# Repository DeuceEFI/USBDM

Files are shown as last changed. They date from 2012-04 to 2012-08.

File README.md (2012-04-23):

# USBDM

JAG 04/16/2012 1500 EST (GMT-0500)

### Introduction

I did not invent the USBDM nor the TBDML or OSBDM that my version of the USBDM PCB is based on, I merely arranged the components so that a home user could etch and solder the components to create a USBDM at home.  This device allows the user to program a blank Freescale microcontroller or to debug the operation of a Freescale microcontroller through the microcontroller's BDM (Background Debug Mode) port.

### Goals

Core specs:

 * USB Type A male connector
 * This USBDM is USB bus powered and will power the target microcontroller (if the target board draws less than 100mA to program the target MCU).
 * No other BDM is necessary to program the Freescale MCU used on the USDBM board, you can program the initial USBDM program through the USB connector.
 * Low cost: components to build this version of the USBDM PCB are approximately $15 USD.
 * Software is available for Windows and Linux host systems from http://sourceforge.net/projects/usbdm/files/

PCB size is to be as small as possible to fit into a USB Type-A female socket on a laptop.

### Links:
 * Sourceforge description: http://usbdm.sourceforge.net/USBDM_V4.9/USBDM_JS16/html/index.html

### Features:

This version of the code & extended hardware provides the following features:

 * A single BDM interface for programming and debugging of the following targets:
   * HCS12 (including those without SYNC feature (e.g. 9S12DP256B)
   * HCS12X
   * HCS08
   * Coldfire V1 microcontrollers

 * No re-flashing of the BDM is required when changing between targets
 * Compatible IDEs
   * Codewarrior V10.1 (Eclipse version)
     * Tested on Windows-XP-32bit, Windows-7-32bit, Windows-7-64bit
     * Tested on Ubuntu-32-bit, Debian-32-bit
   * Codewarrior Legacy versions
   * Codewarrior Development Studio for HCS12(X) V5.1 & CW for Microcontrollers V6.3 (RS08 is not supported)
     * Tested on Windows-XP-32bit, Windows-Vista-32bit
   * Initial support for CodeSourcery Lite for Coldfire
     * Tested on Windows-XP-32bit

 * Trimming of target internal clock (Eclipse version or standalone programming tools only).
 * Higher USB communication speed cf. JB16 version BDMs (USB full speed cf. USB low speed)
 * Windows Vista/Windows 7 compatible
 * Linux compatible
 * Initial Firmware programming may be done without a BDM using the JS16 USB bootloader ROM.
 * The Firmware in the BDM may be automatically updated using an in-circuit-programming (ICP) feature.
 * Hardware is physically small
 * HCS12, HCS08, Coldfire V1 specific features:
   * Target reset detection & control (required for HC12 processors). This allows HC12 processors to be reset into BDM mode as required for debugging.
   * A higher BDM interface speed than the existing JB16 OSBDMs. Up to 56MHz. (BDM clock 28MHz).
   * Automatic re-connection. The software has an option to continuously update the interface speed to prevent loss of communication if the target BDM interface speed changes (as may occur with clock changes on some targets).
   * Control of BDM clock selection in HC12/HCS08/Coldfire microcontrollers. Most of these targets provide an alternative BDM clock selection. This can have advantages when connecting to high speed targets as the alternative clock may operate at a lower speed.
   * Trial-and-error determination of communication speed for earlier HC12 targets.
   *User prompting for target supply cycling with BKGD low as may be needed for HCS08 targets
 
### Status

For the most up to date status information for the project, refer to this README.md file which is maintained in sync with the schematics by a small team who verify each other's work.

### Changes

Please send any changes that you make to this USBDM back upstream to Andy Goss' copy at https://github.com/DeuceEFI/USBDM

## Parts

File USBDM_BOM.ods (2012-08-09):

Component | Quantity | Description | Manufacturer | Part# | Digikey# | Price Each | Sub-Total
C1,C7 | 2 | 100nF capacitor | TDK Corporation | FK20C0G1H104J | 445-4756-ND | $0.96 | $1.92
C2,C4 | 2 | 18pF capacitor | TDK Corporation | FK18C0G1H180J | 445-4762-ND | $0.29 | $0.58
C5,C6 | 2 | 10uF/10V Tantalum capacitor | Kemet | T356C106K010AT | 399-3631-ND | $1.30 | $2.60
C8 | 1 | 470nF capacitor | AVX Corporation | SR205E474MAR | 478-4858-ND | $0.44 | $0.44
D1 | 1 | Green 3mm LED | Kingbright Corporation | WP132XGD | 754-1201-ND | $0.14 | $0.14
P1 | 1 | USB-A Right Angle Plug | Molex Connector Corportation | 48037-0001 | WM17117-ND | $1.70 | $1.70
P2 | 1 | 6 Position 0.1” x 0.1” IDC Ribbon PCB | FCI | 69830-006LF | 609-3082-ND | $1.09 | $1.09
P3 | 1 | 6 Position IDC Socket | FCI | 71600-106LF | 609-2842-ND | $1.18 | $1.18
R1,R2 | 2 | 33 ohm 1% Metal Film resistor | Stackpole Electronics Inc | RNMF14FTC33R0 | S33CACT-ND | $0.14 | $0.28
R3,R5 | 2 | 100K ohm 1% Metal Film resistor | Stackpole Electronics Inc | RNMF18FTC100K | S100KCACT-ND | $0.15 | $0.30
R4 | 1 | 1.5K ohm 1% Metal Film resistor | Stackpole Electronics Inc | RNMF14FTC1K50 | S1.5KCACT-ND | $0.14 | $0.14
R6,R8 | 2 | 47 ohm 1% Metal Film resistor | Stackpole Electronics Inc | RNMF14FTC47R0 | S47CACT-ND | $0.14 | $0.28
R7 | 1 | 1M ohm 1% Metal Film resistor | Stackpole Electronics Inc | RNMF14FTC1M00 | S1MCACT-ND | $0.14 | $0.14
R10 | 1 | 470 ohm 1% Metal Film resistor | Stackpole Electronics Inc | RNMF14FTC470R | S470CACT-ND | $0.14 | $0.14
U1 | 1 | Tri-State Buffer | Texas InstrumentsSN74LV125AD |  | 296-1674-5-ND | $0.55 | $0.55
U2 | 1 | 8 bit MCU | Freescale | MC9S08JS16CWJ | MC9S08JS16CWJ | $2.16 | $2.16
Y1 | 1 | 12MHz Crystal | CTS-Frequency Controls | ATS120B | CTX904-ND | $0.41 | $0.41
 |  |  |  |  | Total Digikey Order |  | $14.05

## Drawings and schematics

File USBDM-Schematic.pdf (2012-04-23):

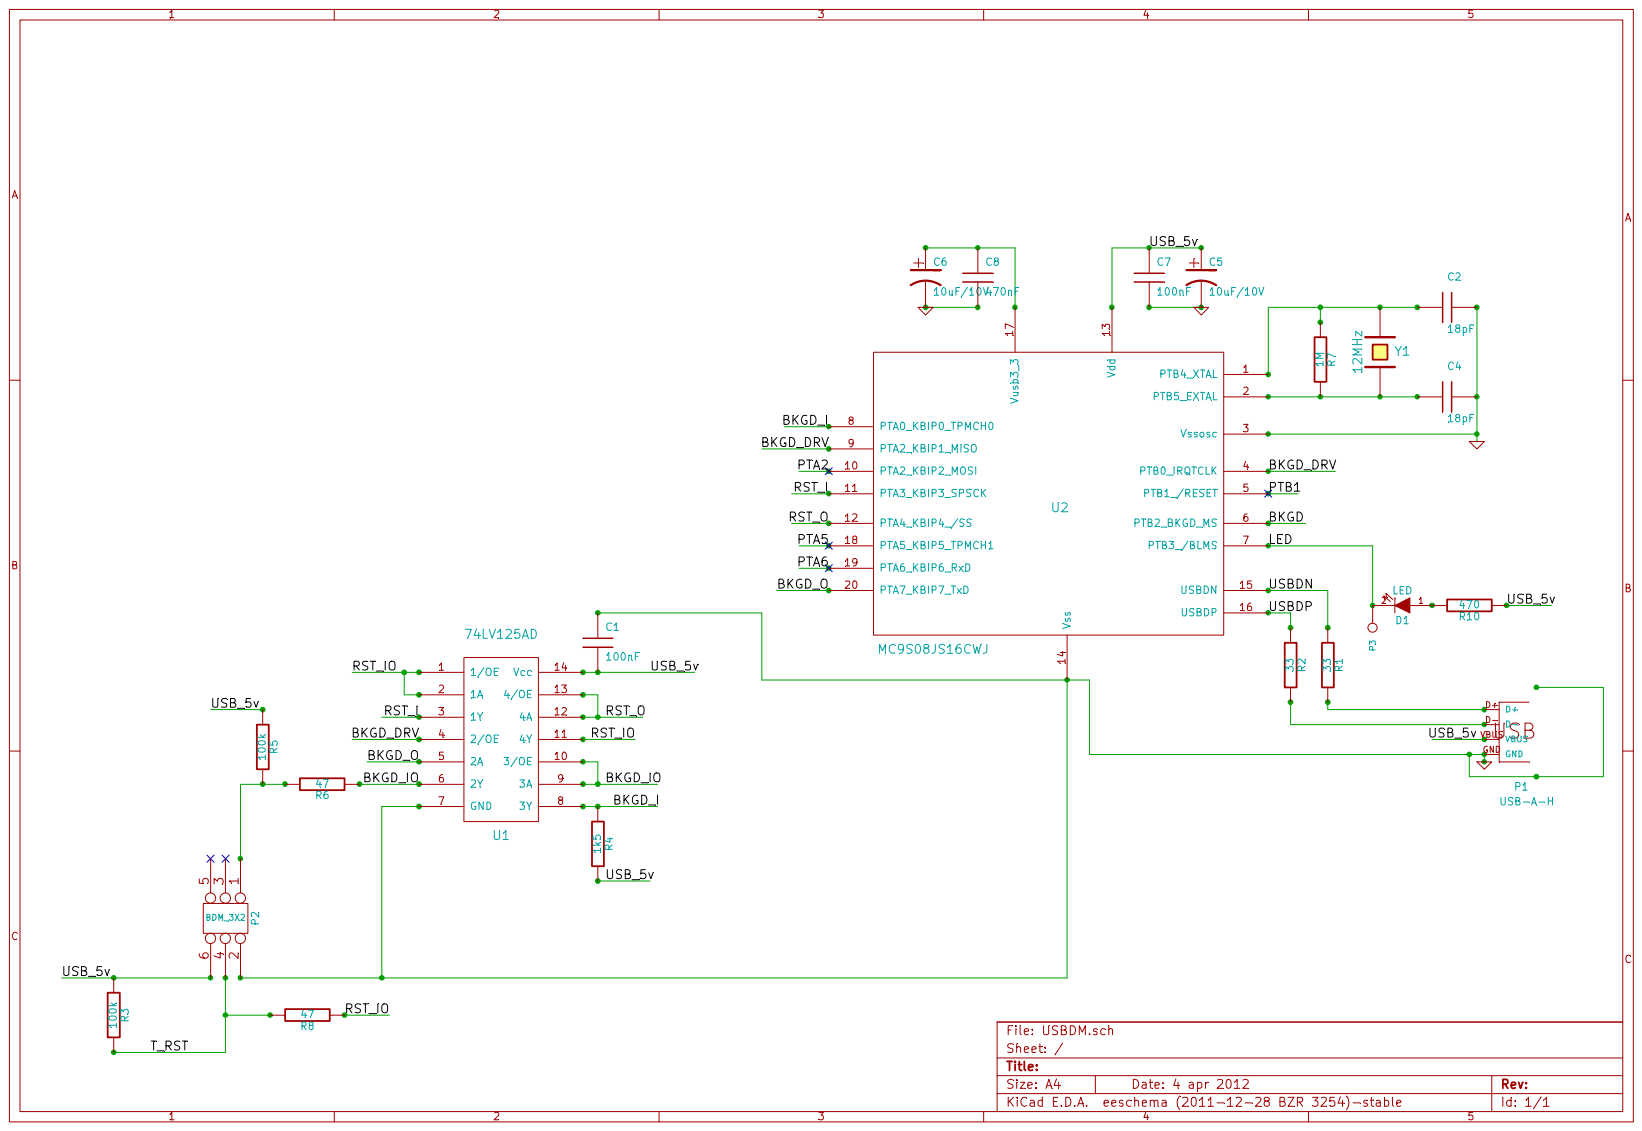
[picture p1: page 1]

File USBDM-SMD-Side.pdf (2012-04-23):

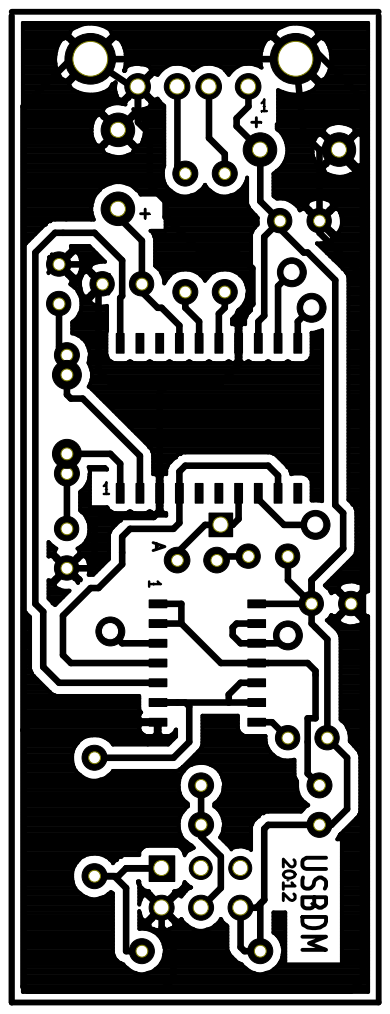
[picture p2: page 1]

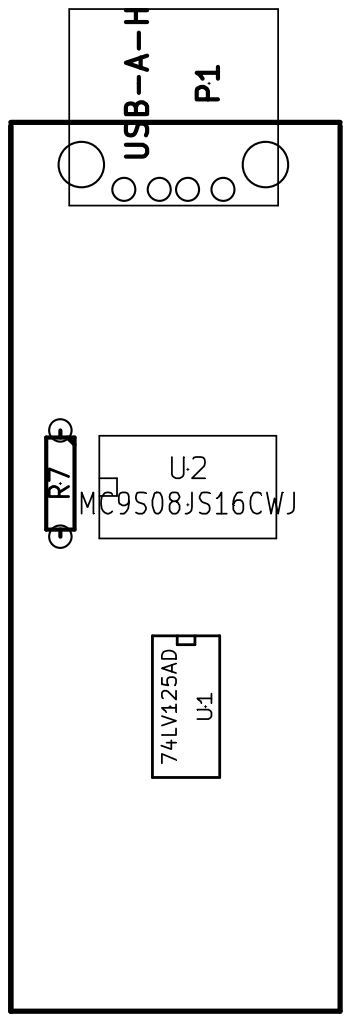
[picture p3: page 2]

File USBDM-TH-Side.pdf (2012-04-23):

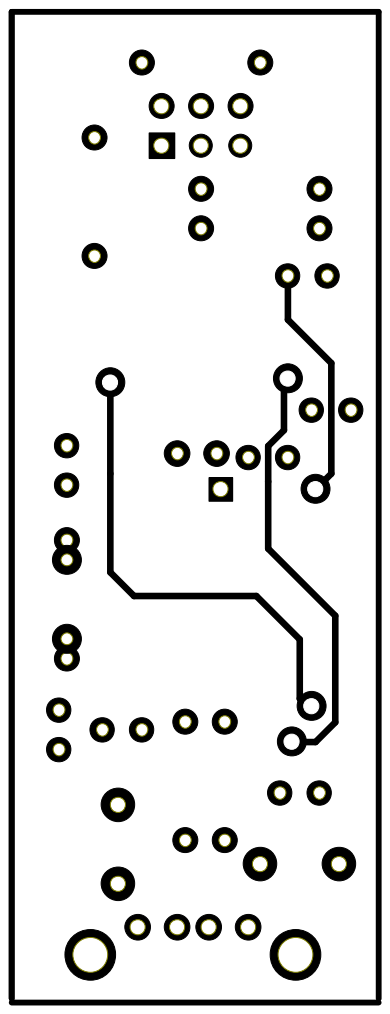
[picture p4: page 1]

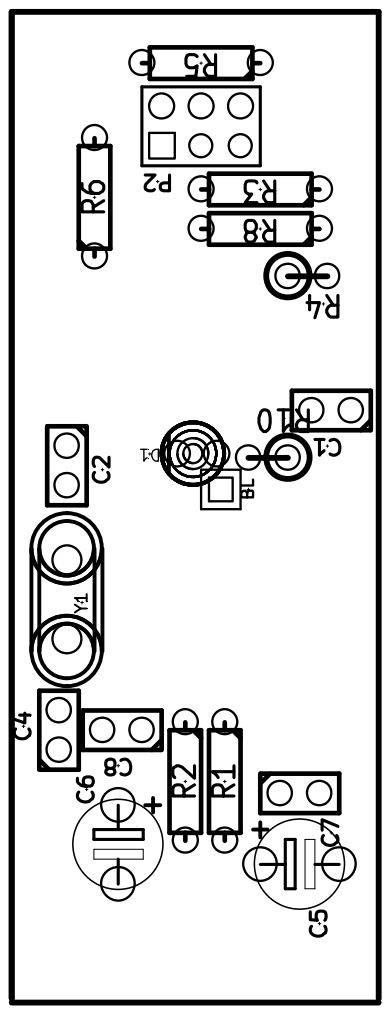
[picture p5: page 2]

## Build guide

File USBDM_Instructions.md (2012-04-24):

# USBDM Flashing instructions

JAG 04/22/2012 1700 EST (GMT-0500)

## Initial programming of USBDM bootloader into BDM Flash.

 * Download the BOOTLOADER GUI from Freescale, you will need this to load the initial USB driver for the Freescale JS16 MCU and to program the USBDM firmware (note this is Windows 32-bit only, sorry).  Link: http://www.freescale.com/webapp/sps/site/prod_summary.jsp?code=DEMO9S08JS16&fpsp=1&tab=Design_Tools_Tab#
 * The JS16 has a built-in USB bootloader. This is used with the provided JS16 Bootloader GUI to initially program the JS16.
 * If the JS16 MCU is completely unprogrammed you can simply plug it in, otherwise tie the BLMS pin low before doing so.
 * The same driver is used by the JS16 Bootloader as used by the USBDM software. The instructions in USB Driver Installation may be followed with the obvious substitution of JS16 Bootloader for USBDM where necessary. Link to USBDM Driver: http://usbdm.sourceforge.net/USBDM_V4.9/USBDM_JS16/html/driver_page.html
 * Start the JS16 Bootloader.
   * # Select the appropriate USBDM firmware to load to the device.
   * Press Program to program the device. There is no progress dialogue but after a short wait a confirmation should appear.
   * Note that this programming is only needed once. You may notice that the programmer gives a error message similar to:
       Doing CRC ...
       CRC Checksum Error
       Error while doing CRC.
    This indicates that the Flash image does not have a valid CRC. USBDM does not use the CRC feature available in the JS16 and hence this error message is to be expected and may be ignored.
 * For a Debian Linux based PC, use the following command to install the pre-requisite packages: 
   * apt-get install tcl8.5 libwxgtk2.8-0 libwxgtk2.8-dbg libstdc++5 libxerces-c3.1
 * At this time you will need to download and install CodeWarrior for MCUs (Linux version) to be able to use the standalone programming utilities as they rely on some libraries from CodeWarrior.  Several people are looking into this to see how to trim down the 2.7GB installation of CW.  Here is a link to download the "Special Edition: CodeWarrior for Microcontrollers 10.2 (Eclipse, Linux hosted) http://www.freescale.com/webapp/sps/site/overview.jsp?code=CW_SPECIALEDITIONS or try this one: http://cache.freescale.com/lgfiles/devsuites/MCU/CW_MCU_v10.2_SE.tar
 * Extract the USBDM archive
   * cd into the /files directory
   * Next you will need to do chmod +x Install_USBDM
   * Now you can run ./Install_USBDM to update your CodeWarrior install so that you can use the USBDM with it.
 * If you don't wish to use CodeWarrior, then you can cd into the Utilities directory and then you will need to chmod +x /*FlashProgrammer/* so that you can run the programming utility.

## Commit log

2012-04-16 Initial commit of files
    [USBDM.brd, USBDM.dsn, USBDM.sch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]
2012-04-16 Updated README.md and USBDM.brd/.pro files
    [USBDM.brd]
2012-04-23 Added KiCAD libraries/started Flashing Instructions
2012-08-09 Updated R3/R5 and R7 Manufacturer and Digikey part numbers since Digikey no longer has the others in stock.
    [USBDM_BOM.ods]
